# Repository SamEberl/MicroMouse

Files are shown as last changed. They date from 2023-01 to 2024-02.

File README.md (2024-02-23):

# MicroMouse
Team Mousterminds

Watch the video (https://www.youtube.com/watch?v=3XfnXp3Lqvg)

Watch the video (https://www.youtube.com/watch?v=xDqnK-Nyn3c)

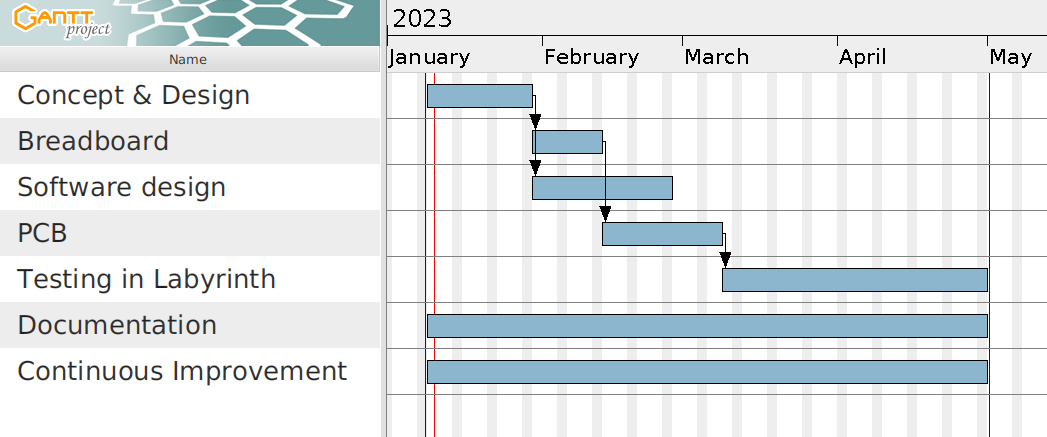
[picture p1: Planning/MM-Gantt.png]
Gantt


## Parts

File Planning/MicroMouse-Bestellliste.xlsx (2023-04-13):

Bestellnummer | Beschreibung | Menge | Einzelpreis | Gesamtpreis | Link
603-CC805MKX5R8BB226 | Kondensator aus mehreren Keramikschichten MLCC - SMD/SMT 25 V 22 uF X5R 0805 20% | 3 | 0.39 | 1.17 | https://www.mouser.de/ProductDetail/YAGEO/CC0805MKX5R8BB226
581-0805ZD225K | Kondensator aus mehreren Keramikschichten MLCC - SMD/SMT 10V 2.2uF X5R 0805 10% | 6 | 0.22 | 1.32 | https://www.mouser.de/ProductDetail/KYOCERA-AVX/0805ZD225KAT2A
581-0805ZD106K | Kondensator aus mehreren Keramikschichten MLCC - SMD/SMT 10V 10uF X5R 0805 10% | 16 | 0.23 | 3.68 | https://www.mouser.de/ProductDetail/KYOCERA-AVX/0805ZD106KAT2A
581-THJB106K010RJN | Tantalkondensatoren - fest für SMD 10UF 10V 10% TOL. | 2 | 0.81 | 1.62 | https://www.mouser.de/ProductDetail/KYOCERA-AVX/THJB106K010RJN
80-C0805C103K8RAUTO | Kondensator aus mehreren Keramikschichten MLCC - SMD/SMT 10V .01uF X7R 0805 10% AEC-Q200 | 2 | 0.09 | 0.18 | https://www.mouser.de/ProductDetail/KEMET/C0805C103K8RACAUTO
 | 15pf | 7 | 0.188 | 1.316 | https://www.mouser.de/ProductDetail/KEMET/C0805C150G4HACTU?qs=W0yvOO0ixfE46ssbvUt3oQ%3D%3D
 | 0.1uF | 18 | 0.122 | 2.196 | https://www.mouser.de/ProductDetail/KEMET/C0805C104K5RAC7411?qs=jbRM9o5BbzPcVXF0wW9AYg%3D%3D
 | 1uF | 4 | 0.141 | 0.564 | https://www.mouser.de/ProductDetail/TAIYO-YUDEN/UMK212B7105KG-T?qs=PzICbMaShUdi76GLXMVYcA%3D%3D
 | 44uF (actually 47uF) | 4 | 0.395 | 1.58 | https://www.mouser.de/ProductDetail/Murata-Electronics/GRM219R60J476ME44D?qs=I53XXhTNm8tggcUcTH0Mag%3D%3D
652-CR0805AFX1003ELF | Dickfilmwiderstände - SMD ResA 0805 100k 1% 125mW TC100 | 4 | 0.09 | 0.36 | https://www.mouser.de/ProductDetail/Bourns/CR0805AFX-1003ELF
652-CR0805FX-1002ELF | Dickfilmwiderstände - SMD 10K 1% | 25 | 0.09 | 2.25 | https://www.mouser.de/ProductDetail/Bourns/CR0805-FX-1002ELF?qs=tknLyCMIRbPr%252BDD0s0nG9g%3D%3D
652-CR0805FX-2002ELF | Dickfilmwiderstände - SMD 20K 1% | 6 | 0.09 | 0.54 | https://www.mouser.de/ProductDetail/Bourns/CR0805-FX-2002ELF?qs=mEbcl8R%252Bl%252Bv8rqM1zQjjRA%3D%3D
71-TNPU080550K0HZEN0 | Dünnfilmwiderstände - SMD 1/8W 50Kohms 0.02% 5ppm | 2 | 5.29 | 10.58 | https://www.mouser.de/ProductDetail/Vishay-Draloric/TNPU080550K0HZEN00?qs=bAKSY%2FctAC6izmQ%2Fvv4TzQ%3D%3D
652-CR0805FX-1653ELF | Dickfilmwiderstände - SMD 165K 1% | 2 | 0.09 | 0.18 | https://www.mouser.de/ProductDetail/Bourns/CR0805-FX-1653ELF?qs=Woncl1%2FcWdij3lPmznyaRw%3D%3D
71-CCF55118RFKE36 | Metallschichtwiderstände - Durchgangsloch 1/4watt 118ohms 1% Rated to 1/2watt | 2 | 0.28 | 0.56 | https://www.mouser.de/ProductDetail/Vishay-Dale/CCF55118RFKE36
279-YR1B619RCC | Metallschichtwiderstände - Durchgangsloch 619Ohm 1/4W 15PPM | 2 | 0.58 | 1.16 | https://www.mouser.de/ProductDetail/TE-Connectivity-Holsworthy/YR1B619RCC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
594-MBA02040C1330FRP | Metallschichtwiderstände - Durchgangsloch 0.4W 133ohm 1% 50ppm 200V | 2 | 0.23 | 0.46 | https://www.mouser.de/ProductDetail/Vishay-Beyschlag/MBA02040C1330FRP00
594-5063JD698R0F1 | Metallschichtwiderstände - Durchgangsloch .4watt 698ohms 1% 1/8watt body size | 2 | 0.41 | 0.82 | https://www.mouser.de/ProductDetail/Vishay-Beyschlag/MBA02040C6980FC100
71-RN55D-F-113 | Metallschichtwiderstände - Durchgangsloch 1/8watt 113ohms 1% 100ppm | 2 | 0.54 | 1.08 | https://www.mouser.de/ProductDetail/Vishay-Dale/RN55D1130FB14
71-CCF55357RFKE36 | etallschichtwiderstände - Durchgangsloch 1/4watt 357ohms 1% Rated to 1/2watt | 2 | 0.28 | 0.56 | https://www.mouser.de/ProductDetail/Vishay-Dale/CCF55357RFKE36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
71-CMF50174R00FHEB | Metallschichtwiderstände - Durchgangsloch 1/4watt 174ohms 1% | 2 | 0.71 | 1.42 | https://www.mouser.de/ProductDetail/Vishay-Dale/CMF50174R00FHEB
71-CMF50549R00FHEB | Metallschichtwiderstände - Durchgangsloch 1/4watt 549ohms 1% | 2 | 0.71 | 1.42 | https://www.mouser.de/ProductDetail/Vishay-Dale/CMF50549R00FHEB
 | 1 Ohm | 7 | 0.188 | 1.316 | https://www.mouser.de/ProductDetail/Vishay-Dale/CRCW08051R00FKEAC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
 | 120 Ohm | 10 | 0.188 | 1.88 | https://www.mouser.de/ProductDetail/ROHM-Semiconductor/SDR10EZPJ121
 | 1 kOhm | 4 | 0.432 | 1.728 | https://www.mouser.de/ProductDetail/YAGEO/RP0805BRD071KL?qs=sGAEpiMZZMtlubZbdhIBIPTwcdbU5mXWLP5qRYmkN6Q%3D
 | 22,1 kOhm | 4 | 1.18 | 4.72 | https://www.mouser.de/ProductDetail/Panasonic/ERA-6ARB2212V
80-L0805R2R2MPWRT | Leistungsinduktivitäten – SMD 0805 2.2uH 20% 175mA | 3 | 0.23 | 0.69 | https://www.mouser.de/ProductDetail/KEMET/L0805R2R2MPWRT?qs=sGAEpiMZZMv126LJFLh8y42QR4PIBQZFJEeP7lzma18%3D
 | 6,8 uH | 5 | 0.677 | 3.385 | https://www.mouser.de/ProductDetail/Bourns/SDR0805-6R8ML?qs=uD%2FoUDWqfvRMWomOplYMJg%3D%3D
SS12 | Diode Schottky Dioden & Gleichrichter 1A, 20V, Schottky Rectifier DO-214AC | 3 | 0.442 | 1.326 | https://www.mouser.de/ProductDetail/Taiwan-Semiconductor/SS12?qs=JV7lzlMm3yJmZoP3vIhYAg%3D%3D
SM0805HCL | Standard-LEDs - SMD Red 635 nm Water Clear LED chipled | 3 | 0.546 | 1.638 | https://www.mouser.de/ProductDetail/Bivar/SM0805HCL?qs=jaLxTFIJCiunRhy8mE7Amw%3D%3D
926-LM2937IMP3.3NOPB | LDO Spannungs-Regulator 400 mA LDO REG | 2 | 2.55 | 5.1 | https://www.mouser.de/ProductDetail/Texas-Instruments/LM2937IMP-3.3-NOPB?qs=X1J7HmVL2ZFVwNOBcwuxRQ%3D%3D
825-6933 | Texas Instruments Abwärtswandler 1A 6 V Abwärtsregler 0,9 V 3 V / 17 V Einstellbar SMD 8-Pin | 5 | 2.058 | 10.29 | https://de.rs-online.com/web/p/abwarts-regler/8256933
LMR51420XDDCR | Schaltspannungsregler SIMPLE SWITCHER power converter 4.5-V to 36-V, 2-A, synchronous buck with 40-uA IQ | 5 | 1.47 | 7.35 | https://www.mouser.de/ProductDetail/Texas-Instruments/LMR51420XDDCR?qs=vvQtp7zwQdN6fBqQU4azxw%3D%3D
DRV8411RTER | Motor / Bewegung / Zündungscontroller und Treiber 1.65-V to 11-V, 4-A, dual H-bridge motor driver with current regulation | 5 | 2.02 | 10.1 | https://www.mouser.de/ProductDetail/Texas-Instruments/DRV8411RTER?qs=Y0Uzf4wQF3l%2F0rMZ4jyBhg%3D%3D
ECS-160-20-4X-B-DN | Quarze 16MHz 30ppm 20pF 40 ohms Quartz Crystal 3.5mm | 5 | 0.686 | 3.43 | https://www.mouser.de/ProductDetail/ECS/ECS-160-20-4X-B-DN?qs=gmcn8Ik9O3HSyHFy%252BkxJ1A%3D%3D
 |  |  | Summe | 87.969

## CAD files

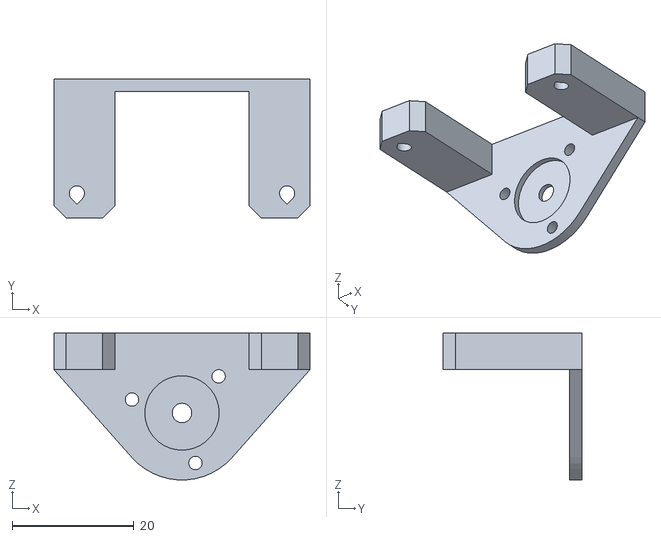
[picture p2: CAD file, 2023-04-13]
Hardware/MotorMount2.STL
42.0 x 22.8 x 24.1

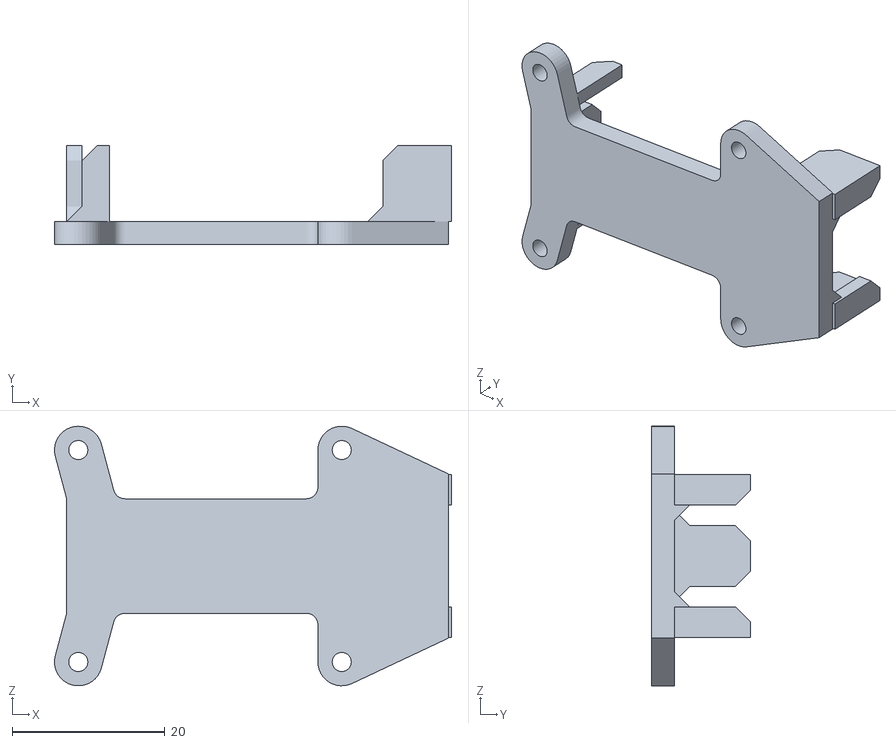
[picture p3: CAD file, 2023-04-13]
Hardware/9VBatMountHorizontal.STL
52.0 x 13.0 x 34.0

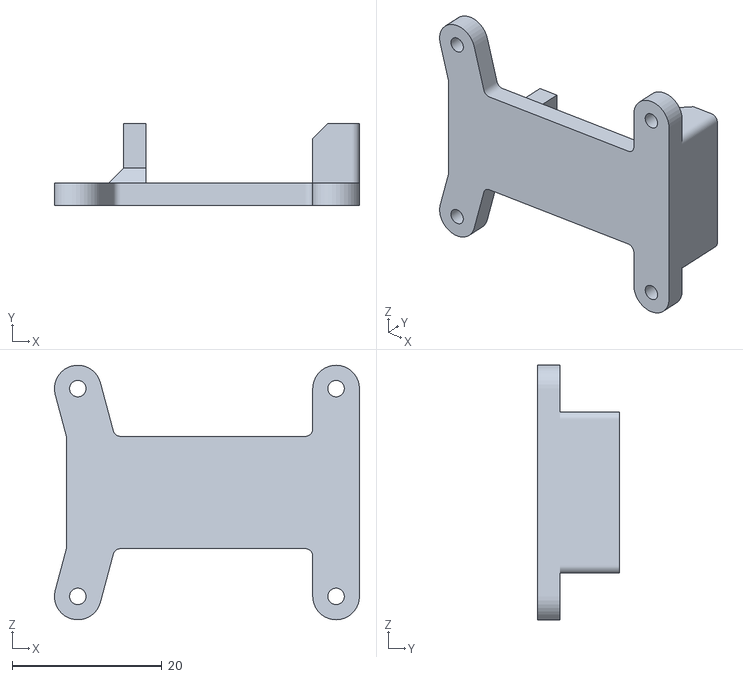
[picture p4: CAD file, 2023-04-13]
Hardware/9VBatMountVertical.STL
40.7 x 11.0 x 34.0

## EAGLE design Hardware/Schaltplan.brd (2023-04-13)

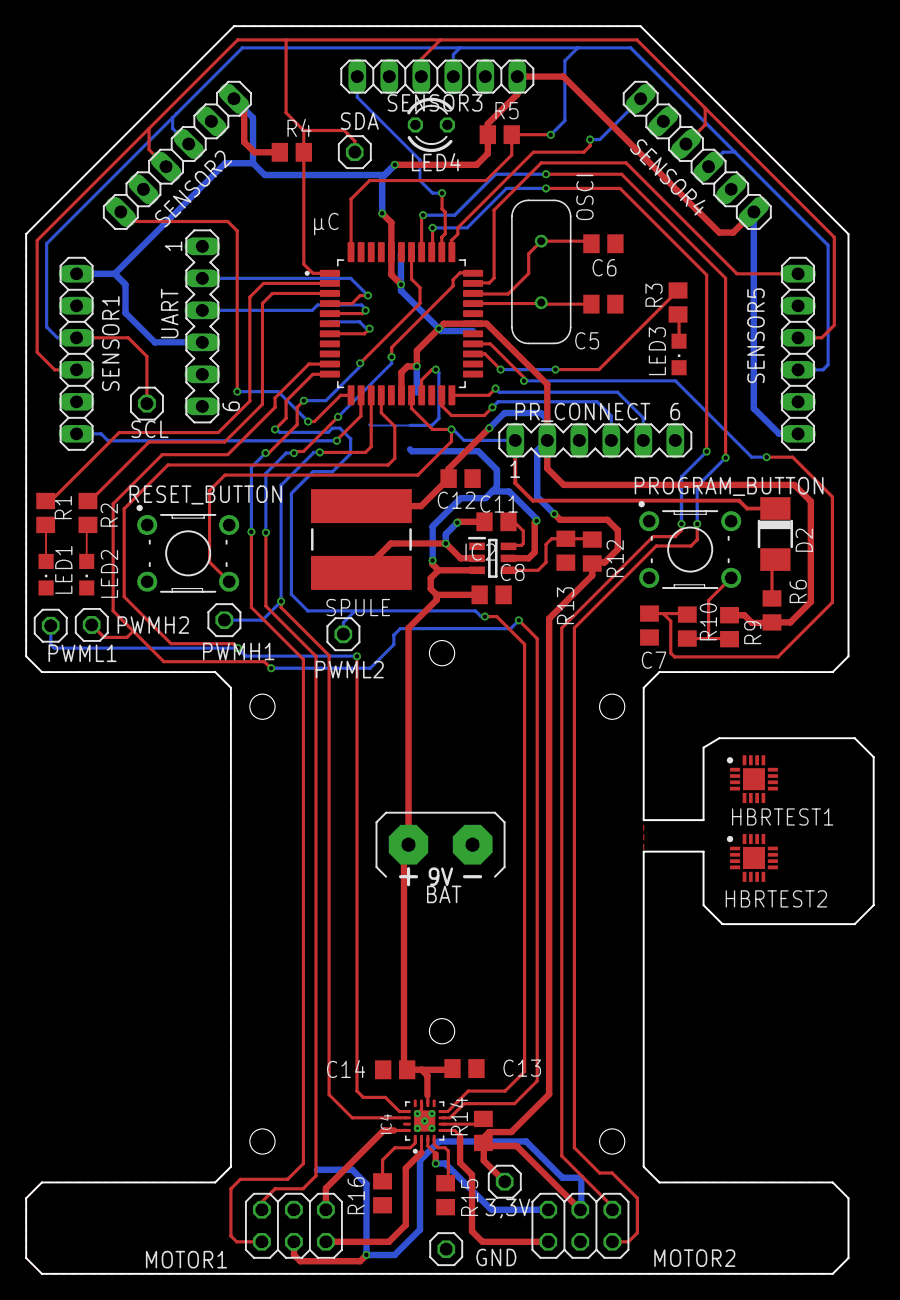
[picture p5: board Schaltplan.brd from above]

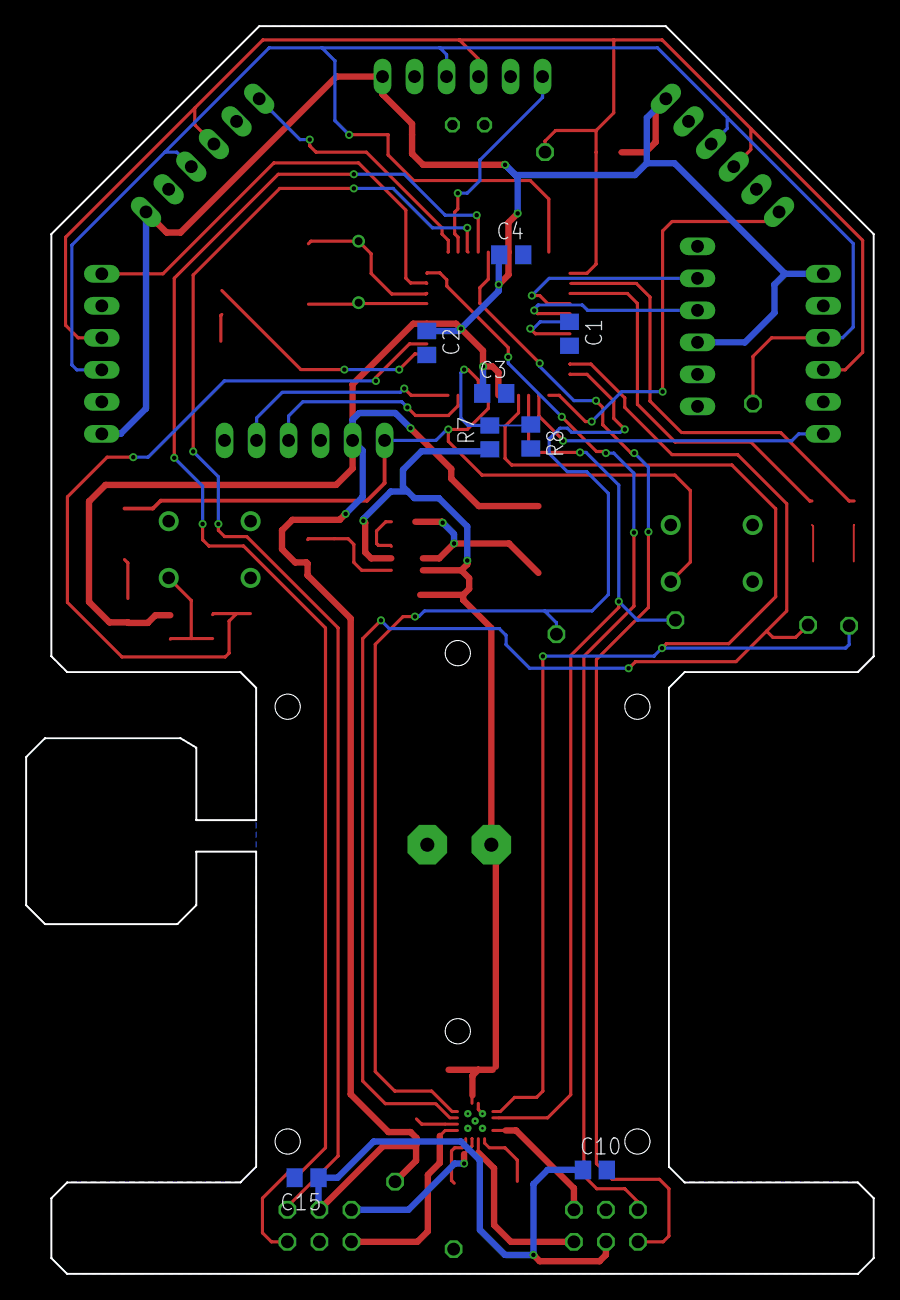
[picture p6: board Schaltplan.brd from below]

Board: 2 copper layers, 67.2 x 99.0 mm, 61 parts (8 on the bottom side), 46 nets.

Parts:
3,3V: 1X01
BAT: AB9V
C1: 10μ; C0805
C2, C3, C4: 0,1 μF; C0805
C5, C6: 15pf; C0805
C7: 1 µF; C0805
C8: 2.2 µF; C0805
C10, C14, C15: 100 nF; C0805
C11: 0,1 µF; C0805
C12: 44 µF; C0805
C13: 10 µF; C0805
D2: DO-214AC
GND: 1X01
HBRTEST1, HBRTEST2: DRV8411RTER; QFN50P300X300X80-17N
IC2: LMR51420XDDCR; SOT95P280X110-6N
IC4: DRV8411RTER; QFN50P300X300X80-17N
LED1, LED2, LED3: CHIPLED_0805
LED4: TLLR4400; LED3MM
MOTOR1, MOTOR2: 2X03
OSCI: ECS-160-20-4X-B-DN; XTAL_ECS-160-20-4X-B-DN
PROGRAM_BUTTON: B3F-1000; SW_B3F-1000
PR_CONNECT: MA06-1
PWMH1, PWMH2: 1X01
PWML1, PWML2: 1X01
R1, R2, R3: 680 Ω; R0805
R4, R5, R6, R8, R9, R14: 10 kΩ; R0805
R7: 20 kΩ; R0805
R10: 1kΩ; R0805
R12: 100 kΩ; R0805
R13: 22,1 kΩ; R0805
R15, R16: 1 Ω; R0805
RESET_BUTTON: B3F-1000; SW_B3F-1000
SCL: 1X01
SDA: 1X01
SENSOR1, SENSOR2, SENSOR3, SENSOR4, SENSOR5: 1X06
SPULE: SDR0805-6R8ML; SDR08056R8ML
UART: MA06-1
µC: DSPIC33FJ64MC804-I/PT; QFP80P1200X1200X120-44N

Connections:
3,3V: 3,3V.1, C2.1, C3.1, C4.1, C10.1, C12.1, C15.1, MOTOR1.4, MOTOR2.4, PR_CONNECT.2, R4.1, R5.1, R6.2, R9.2, R12.1, R14.1, SENSOR1.1, SENSOR2.1, SENSOR3.1, SENSOR4.1, SENSOR5.1, SPULE.2, UART.4, µC.17, µC.28, µC.40
9V: BAT.+, C8.1, C13.1, C14.2, IC2.3, IC2.5, IC4.10, R7.1
CRY1: C5.2, OSCI.1, µC.30
CRY2: C6.2, OSCI.2, µC.31
GND: BAT.-, C1.2, C2.2, C3.2, C4.2, C5.1, C6.1, C7.2, C8.2, C10.2, C12.2, C13.2, C14.1, C15.2, GND.1, IC2.1, IC4.11, IC4.17, IC4.18, IC4.19, IC4.20, IC4.21, IC4.22, LED1.C, LED2.C, LED3.C, LED4.A, LED4.K, MOTOR1.3, MOTOR2.3, PROGRAM_BUTTON.1, PROGRAM_BUTTON.2, PR_CONNECT.3, R8.2, R13.2, R15.2, R16.2, RESET_BUTTON.1, RESET_BUTTON.2, SENSOR1.2, SENSOR2.2, SENSOR3.2, SENSOR4.2, SENSOR5.2, UART.1, UART.6, µC.6, µC.16, µC.29, µC.39
GPIO0_1: SENSOR1.6, µC.13
GPIO0_2: SENSOR2.6, µC.12
GPIO0_3: SENSOR3.6, µC.35
GPIO0_4: SENSOR4.6, µC.34
GPIO0_5: SENSOR5.6, µC.32
KANAL1_A: MOTOR2.6, µC.36
KANAL1_B: MOTOR2.5, µC.37
KANAL2_A: MOTOR1.6, µC.38
KANAL2_B: MOTOR1.5, µC.33
LED1: R1.2, µC.2
LED2: R2.2, µC.3
LED3: R3.2, µC.25
M1+: IC4.2, MOTOR1.2
M1-: IC4.16, MOTOR1.1
M2+: IC4.3, MOTOR2.2
M2-: IC4.5, MOTOR2.1
MCLR: D2.C, PR_CONNECT.1, RESET_BUTTON.4, µC.18
unnamed: C1.1, µC.7
unnamed: PROGRAM_BUTTON.4, R9.1, R10.2
unnamed: LED2.A, R2.1
unnamed: LED1.A, R1.1
unnamed: C11.2, IC2.6
unnamed: LED3.A, R3.1
unnamed: D2.A, R6.1
unnamed: C11.1, IC2.2, SPULE.1
unnamed: IC4.6, R14.2
unnamed: IC2.4, R12.2, R13.1
unnamed: IC4.1, R16.1
unnamed: IC4.4, R15.1
PGC1: PR_CONNECT.5, µC.22
PGD1: PR_CONNECT.4, µC.21
PWMH1: IC4.14, PWMH1.1, µC.14
PWMH2: IC4.7, PWMH2.1, µC.10
PWML1: IC4.13, PWML1.1, µC.15
PWML2: IC4.8, PWML2.1, µC.11
SCL: R5.2, SCL.1, SENSOR1.3, SENSOR2.3, SENSOR3.3, SENSOR4.3, SENSOR5.3, µC.44
SDA: R4.2, SDA.1, SENSOR1.4, SENSOR2.4, SENSOR3.4, SENSOR4.4, SENSOR5.4, µC.1
SW1: C7.1, R10.1, µC.26
UART_RX: UART.2, µC.4
UART_TX: UART.3, µC.5
VREF: R7.2, R8.1, µC.19

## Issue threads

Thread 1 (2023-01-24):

Purchase links

SamEberl, 2023-01-24:
# Parts we might want to buy
Spannungsregler:
- agreed upon in whatsapp -> https://www.mouser.de/ProductDetail/Texas-Instruments/LMR51420XDDCR?qs=vvQtp7zwQdN6fBqQU4azxw%3D%3D
- still lying about in lab -> https://www.mouser.de/ProductDetail/Texas-Instruments/LMR33630ADDAR?qs=r5DSvlrkXmJQkBTqgVdiDA%3D%3D

H-Brücke:
- if our motor is brushed -> https://www.mouser.de/ProductDetail/Toshiba/TB67H451AFNGEL?qs=Wj%2FVkw3K%252BMArV7aRaH6JgA%3D%3D

@ItsILuigi @EEE26

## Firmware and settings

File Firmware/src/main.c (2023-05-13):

/* 
 * File:   main.c
 * Author: Alexander Lenz
 *
 * Created on 27 Nov 2020, 09:36
 */


/// Configuration Bits---------------------------

// FBS
#pragma config BWRP = WRPROTECT_OFF     // Boot Segment Write Protect (Boot Segment may be written)
#pragma config BSS = NO_FLASH           // Boot Segment Program Flash Code Protection (No Boot program Flash segment)

// FGS
#pragma config GWRP = OFF               // General Code Segment Write Protect (User program memory is not write-protected)
#pragma config GSS = OFF                // General Segment Code Protection (User program memory is not code-protected)

// FOSCSEL
#pragma config FNOSC = FRC                 // Start with Internal RC Oscillator
#pragma config IESO = OFF                // Internal External Switch Over Mode (Start-up device with FRC, then automatically switch to user-selected oscillator source when ready)

// FOSC
#pragma config POSCMD = HS             // Primary Oscillator Source (HS Oscillator Mode)
#pragma config OSCIOFNC = OFF           // OSC2 Pin Function (OSC2 pin has clock out function)
#pragma config IOL1WAY = OFF            // Peripheral Pin Select Configuration (Allow Multiple Re-configurations)
#pragma config FCKSM = CSECMD           // Clock Switching and Monitor (Both Clock Switching and Fail-Safe Clock Monitor are enabled)

// FWDT
#pragma config WDTPOST = PS1            // Watchdog Timer Postscaler (1:1)
#pragma config WDTPRE = PR128           // WDT Prescaler (1:128)
#pragma config WINDIS = OFF             // Watchdog Timer Window (Watchdog Timer in Non-Window mode)
#pragma config FWDTEN = OFF             // Watchdog Timer Enable (Watchdog timer enabled/disabled by user software)

// FPOR
#pragma config FPWRT = PWR128           // POR Timer Value (128ms)
#pragma config ALTI2C = OFF             // Alternate I2C  pins (I2C mapped to SDA1/SCL1 pins)
#pragma config LPOL = OFF                // Motor Control PWM Low Side Polarity bit (PWM module low side output pins have active-high output polarity)
#pragma config HPOL = OFF                // Motor Control PWM High Side Polarity bit (PWM module high side output pins have active-high output polarity)
#pragma config PWMPIN = ON              // Motor Control PWM Module Pin Mode bit (PWM module pins controlled by PORT register at device Reset)

// FICD
#pragma config ICS = PGD1               // Comm Channel Select (Communicate on PGC1/EMUC1 and PGD1/EMUD1)
#pragma config JTAGEN = OFF             // JTAG Port Enable (JTAG is Disabled)



/// Include headers-------------------------------
#include "xc.h"
#include "bsw.h"
#include "asw.h"
/// Defines----------------------------
#define SEVEN_MEG_OSC 0//set to 1 if we use slow (7.3728 MHz) oscillator and not 16 MHz
/*
 * 
 */

int main() 
{
//    int pinStatus;
    
#if (SEVEN_MEG_OSC == 0) 
     /*** oscillator setup 
--------------------------------------------------
     * The external oscillator runs at 16MHz
     * PLL is used to generate 53.3 MHz clock (FOSC)
     * The relationship between oscillator and cycle frequency: FCY = 
FOSC/2
     * Have a look at "PLL Configuration" paragraph in the mcu manual
    
     * Result: FCY = 0.5 * (16MHz*20/(3*2)) = 26.666 MIPS, Tcycle=37.5nsec
    
---------------------------------------------------------------------***/
    PLLFBDbits.PLLDIV = 18;                      //set PPL to M=20 (18+2)
    CLKDIVbits.PLLPRE = 1;            //N1 = input/3
    CLKDIVbits.PLLPOST = 0;           //N2 = output/2
    
    
    
#else //Below the 7.3728 Setup 
    
         /*** oscillator setup 
--------------------------------------------------
     * The external oscillator runs at 7.3728 MHz
     * PLL is used to generate 53.3 MHz clock (FOSC)
     * The relationship between oscillator and cycle frequency: FCY = 
FOSC/2
     * Have a look at "PLL Configuration" paragraph in the mcu manual
    
     * Result: FCY = 0.5 * (7.3728 MHz*29/(2*2)) = 26.73 MIPS, which is 
          * not exactl Tcycle=37.5nsec, but close enough for our purposes
    
---------------------------------------------------------------------***/
    PLLFBDbits.PLLDIV = 27;                      //set PPL to M=29 (27+2)
    CLKDIVbits.PLLPRE = 0;            //N1 = input/2
    CLKDIVbits.PLLPOST = 0;           //N2 = output/2
#endif //SEVEN_MEG_OSC == 0
    
    
        /* Clock switch to incorporate PLL*/
    __builtin_write_OSCCONH( 0x03 );            // Initiate Clock Switch to Primary

    // Oscillator with PLL (NOSC=0b011)
    __builtin_write_OSCCONL( OSCCON || 0x01 );  // Start clock switching
    
    while( OSCCONbits.COSC != 0b011 );
    
    // In reality, give some time to the PLL to lock
    while (OSCCONbits.LOCK != 1); //Wait for PPL to lock
    
    //INIT PROGRAM
    bsw_init();
    asw_init();
    init_end();
    
    //IDLE
    while(1)
    {
        
    };
 
    
    return 0;
}

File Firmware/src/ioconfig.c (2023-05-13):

#include "xc.h"
#include "ioconfig.h"
#include "general.h"
#include "io_public.h"

static uint8_t buttonPressed = FALSE;

static ButtonPressedCB buttonPressedCB;
static uint8_t buttonPressedInitalized = FALSE;

static ButtonReleasedCB buttonReleasedCB;
static uint8_t buttonReleasedInitalized = FALSE;

void setupIO()
{

    int i;
    AD1PCFGL=0xFFFF; //all pins are now digital, by default they are analogue
    AD1PCFGLbits.PCFG0 = 0; //set AN0 to analogue
    
    // set Sensors as output
    TRISAbits.TRISA7 = 0;   //SEN1
    TRISAbits.TRISA10 = 0;  //SEN2
    TRISAbits.TRISA9 = 0;   //SEN3
    TRISAbits.TRISA4 = 0;   //SEN4
    TRISAbits.TRISA8 = 0;   //SEN5
    
    // set LEDs as output
    TRISCbits.TRISC6 = 0;   //LED1
    TRISCbits.TRISC7 = 0;   //LED2
    TRISCbits.TRISC0 = 0;   //LED3
    
    // set SW1 as input
    TRISCbits.TRISC1 = 1;

    //PIN MAPPING
    
    //before we map, we need to unlock
    __builtin_write_OSCCONL(OSCCON & 0xbf); // clear bit 6 (unlock, they are usually write protected)
    
    // PERIPHERAL receives data from which INPUT  
    RPINR18bits.U1RXR = 24; //mapped to RP24 is U1 RX, CHANGE THIS

    //MOTOR RIGHT
    //PERIPHERAL QEA Encoder 1, receives data from RP19
    RPINR14bits.QEA1R = 19; 
    //PERIPHERAL QEB Encoder 1, receives data from RP20
    RPINR14bits.QEB1R = 20;
    
    //MOTOR LEFT
    //PERIPHERAL QEA Encoder 2, receives data from RP21
    RPINR16bits.QEA2R = 21; 
    //PERIPHERAL QEB Encoder 2, receives data from RP4
    RPINR16bits.QEB2R = 4;
    
    
    //OUTPUT PIN receives data from which PERIPHERAL, 
    //see table 11-2 in datasheet to check peripheral codes
    RPOR12bits.RP25R = 0b00011; //output bin RP25 gets data from peripheral U1 TX 

   
    //after mapping we lock again
     __builtin_write_OSCCONL(OSCCON | 0x40); // Lock PPS registers (lock again!)
     
    for (i = 0; i < 30000; i++); // short dirty delay for changes to take effect,

    SEN1 = SENOFF;
    SEN2 = SENOFF;
    SEN3 = SENOFF;
    SEN4 = SENOFF;
    SEN5 = SENOFF;
}

errorCode changeLEDState(uint8_t ledNr, uint8_t state){
    if(!((state==LEDON)||(state==LEDOFF))) return INVALID_ARGUMENT_ERROR;
    switch(ledNr){
        case 1:
            LED1 = state;
            break;
        case 2:
            LED2 = state;
            break;
        case 3:
            LED3 = state;
            break;
        default:
            return INVALID_ARGUMENT_ERROR;
    }
    return OK;
}

errorCode IO_registerButtonPressedCB(ButtonPressedCB callback){
    buttonPressedCB = callback;
    buttonPressedInitalized = TRUE;
    return OK;
}

errorCode IO_registerButtonReleasedCB(ButtonReleasedCB callback){
    buttonReleasedCB = callback;
    buttonReleasedInitalized = TRUE;
    return OK;
}

void IO_10ms(){
    uint8_t newButtonState = SW1;
    
    if(newButtonState != buttonPressed){
        buttonPressed = newButtonState;
        if(buttonPressed == SW_PRESSED){
            if(buttonPressedInitalized == TRUE) buttonPressedCB();
        }
        else{
            if(buttonReleasedInitalized == TRUE) buttonReleasedCB();
        }
    }
}

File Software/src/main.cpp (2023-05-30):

#include "defs.h"
#include "utils.h"
#include "estimations.h"
#include "algorithm.h"


#include "asw.h"
#include "bsw_api.h"
#include "general.h"
#include "xc.h"

static uint8_t statusAsw = 20;

void incrementStatus(void) {
    statusAsw++;
}

void asw_init(void){
    //TODO INITIALIZE ASW PROGRAM

    // registerButtonPressedCB(&incrementStatus);
    // registerButtonReleasedCB(&incrementStatus);

    int start_x = LABYRINTH_WIDTH-1;
    int start_y = LABYRINTH_HEIGHT-1;

    float rob_x = (start_x*(CELL_SIZE + WALL_WIDTH))+(CELL_SIZE/2)+WALL_WIDTH;
    float rob_y = (start_y*(CELL_SIZE + WALL_WIDTH))+(CELL_SIZE/2)+WALL_WIDTH;
    float rob_dir = M_PI*3/2;

    RobotEst mouseEst = RobotEst(rob_x, rob_y, rob_dir, DISTANCE_WHEELS, MOUSE_WIDTH, MOUSE_HEIGHT);
    CellEst labyrinthEst[LABYRINTH_WIDTH][LABYRINTH_HEIGHT];
    CornerEst cornersEst[LABYRINTH_WIDTH+1][LABYRINTH_HEIGHT+1];
    init_labyrinth(labyrinthEst);
    init_corners(cornersEst);
    Planner planner(start_x, start_y);
}

void asw_10ms(void){
    //TODO 10MS PROCESS FOR ASW
    mouse.measureDistances(labyrinth, corners);

    Point wheel_speed;

    // Update the wheel_speed using the planner function
    planner_update(mouseEst, labyrinthEst, wheel_speed);

    // Set the motor velocities using the wheel_speed array elements
    setMotorVelocity(MOTOR_L, wheel_speed[0]);
    setMotorVelocity(MOTOR_R, wheel_speed[1]);


    mouseEst.updatePosition(renderer, mouse, labyrinthEst, cornersEst);
    mouseEst.localization();


    uint8_t sensorVal;
    getSensorVal(2,&sensorVal);
    if(sensorVal < 100){
        setLEDState(1,ON);
    }
    else{
        setLEDState(1,OFF);
    }
    getSensorVal(4,&sensorVal);
    if(sensorVal < 100){
        setLEDState(2,ON);
    }
    else{
        setLEDState(2,OFF);
    }
    setASWStatus(statusAsw);
}

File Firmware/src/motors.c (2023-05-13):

#include "motors.h"
#include "motorEncoders.h"
#include "params.h"
#include "uartTp.h"
#include "myPWM.h"
#include "motor_public.h"
#include <math.h>
#include <xc.h>
#include <stdlib.h>

#define NUM_ERRORS_STORED 30
#define MOTOR_MAX_VELOCITY 100 //From Datasheet calculated. Probably not really reachable but a good starting point

typedef struct motor{
    int8_t desiredVelocity;
    int8_t actualVelocity;
    double kp;
    double ki;
    double kd;
    int8_t errorList[NUM_ERRORS_STORED];
    int16_t errorSum;
    uint8_t idx;
    double dc;
    uint8_t direction;
}motor;

static motor MotorLeft = {0};
static motor MotorRight = {0};

errorCode updateMotorState(){
    uint16_t temp;
    //Update Motor Left
    //Parameter update
    getParameter(PARAM_BSW_L_KP, &temp);
    MotorLeft.kp = ((double)temp)/1000.0;
    getParameter(PARAM_BSW_L_KI, &temp);
    MotorLeft.ki = ((double)temp)/1000.0;
    getParameter(PARAM_BSW_L_KD, &temp);
    MotorLeft.kd = ((double)temp)/1000.0;
    //Measure Velocity
    MotorLeft.actualVelocity = getMotorLeftVelocity();
    //Update Motor Right
    //Parameter update
    getParameter(PARAM_BSW_R_KP, &temp);
    MotorRight.kp = ((double)temp)/1000.0;
    getParameter(PARAM_BSW_R_KI, &temp);
    MotorRight.ki = ((double)temp)/1000.0;
    getParameter(PARAM_BSW_R_KD, &temp);
    MotorRight.kd = ((double)temp)/1000.0;
    //Measure Velocity
    MotorRight.actualVelocity = getMotorRightVelocity();
    
    return OK;
}

double calcuclateForwardingDC(int8_t desiredVelocity) {
    double dc = ((double)desiredVelocity)/((double)MOTOR_MAX_VELOCITY);
    if(dc < -1.0) return -1.0;
    else if(dc > 1.0) return 1.0;
    return dc;
}

void setSpeed(void){
    uartTp_updateMessageContent(motLDesVel, &MotorLeft.desiredVelocity);
    //uartTp_updateMessageContent(motLActVel, &MotorLeft.actualVelocity);
    uartTp_updateMessageContent(motRDesVel, &MotorRight.desiredVelocity);
    //uartTp_updateMessageContent(motRActVel, &MotorRight.actualVelocity);
    
    //Motor Right
    if(MotorRight.direction == TURN_FORWARD)
        setPWM1Mode(2,DISABLE_H_ENABLE_L);
    else
        setPWM1Mode(2,ENABLE_H_DISABLE_L);
    
    setPWM1DC(2,MotorRight.dc);
    
    //Motor Left
    if(MotorLeft.direction == TURN_FORWARD)
        setPWM1Mode(1,ENABLE_H_DISABLE_L);
    else
        setPWM1Mode(1,DISABLE_H_ENABLE_L);
    
    setPWM1DC(1,MotorLeft.dc);
}

errorCode controlLoopStep(motor* mot){
    int8_t error = mot->desiredVelocity - mot->actualVelocity;
    int8_t lastError = mot->errorList[mot->idx];
    double forwarding_dc = calcuclateForwardingDC(mot->desiredVelocity);
    //increment idx
    (mot->idx)++;
    if(mot->idx == NUM_ERRORS_STORED) mot->idx = 0;
    
    //Update error Sum
    mot->errorSum -= mot->errorList[mot->idx];
    mot->errorList[mot->idx] = error;
    mot->errorSum += mot->errorList[mot->idx];
    
    double p = mot->kp * (double)error;
    double i = mot->ki * (double)mot->errorSum;
    double d = mot->kd * (double)(error-lastError);
    
    //double dc = p+i+d+forwarding_dc;
    double dc = p+i+d;
    if((dc<-0.6)||(dc>0.6)) mot->dc = 0.6;
    else mot->dc = fabs(dc);
    
    if(dc<0.0) mot->direction = TURN_BACKWARD;
    else mot->direction = TURN_FORWARD;
    
    return OK;
}

void motor_init(void){
    MotorLeft.desiredVelocity = 0;    
    MotorRight.desiredVelocity = 0;
    
}

void motor_10ms(void){
    updateMotorState();
    controlLoopStep(&MotorLeft);
    controlLoopStep(&MotorRight);
    setSpeed();
}

errorCode setDesiredVelocity(uint8_t mot, int8_t velocity){
    if((velocity<-MOTOR_MAX_VELOCITY)||(velocity>MOTOR_MAX_VELOCITY)) return INVALID_ARGUMENT_ERROR;
    switch(mot){
        case MOTOR_L:
            MotorLeft.desiredVelocity = velocity;
            break;
        case MOTOR_R:
            MotorRight.desiredVelocity = velocity;
            break;
        default:
            return INVALID_ARGUMENT_ERROR;
    }
    return OK;
}

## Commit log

2023-03-08 add .stl files for 3D print
    [9VBatMountHorizontal.STL, 9VBatMountVertical.STL, MicroMouse-Bestellliste.xlsx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]
2023-03-08 move into hardware folder
    [Schaltplan.sch]
2023-03-23 tighter bat fit, larger screw holes
    [9VBatMountHorizontal.STL]
2023-04-13 commit current state to make fundamental changes to update position
2023-04-13 updated robot and sensor movement
2023-04-16 Disable UART for Testing
2023-04-17 sensor returns right distance & pruning of files
2023-04-26 commit current state to check out other branch
2023-04-26 added localization from sensor values
2023-04-30 fixed bugs in SLAM, added wall_width
    [defs.h, main.cpp]
2023-04-30 started PID controlling the angle
2023-05-10 shortened code for localization
    [main.cpp]
2023-05-10 remove redundant file
    [Schaltplan.sch]
2023-05-13 fixed seeing opposite wall because of noise
    [defs.h]
